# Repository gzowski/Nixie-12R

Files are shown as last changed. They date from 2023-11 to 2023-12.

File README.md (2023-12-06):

# Nixie-12R - Keyboard/GamePad

* Available to purchase from: https://www.etsy.com/uk/shop/PhoenixCustomBoards

* 11 key ortholinear keyboard
* 1 Rotary encoder in the top right
* OLED Display for displaying layer selected
* Pro Micro compatible
  
### [Info](#Info) || [Parts](#Parts) || [Assembly Guide](#Assembly-Guide)

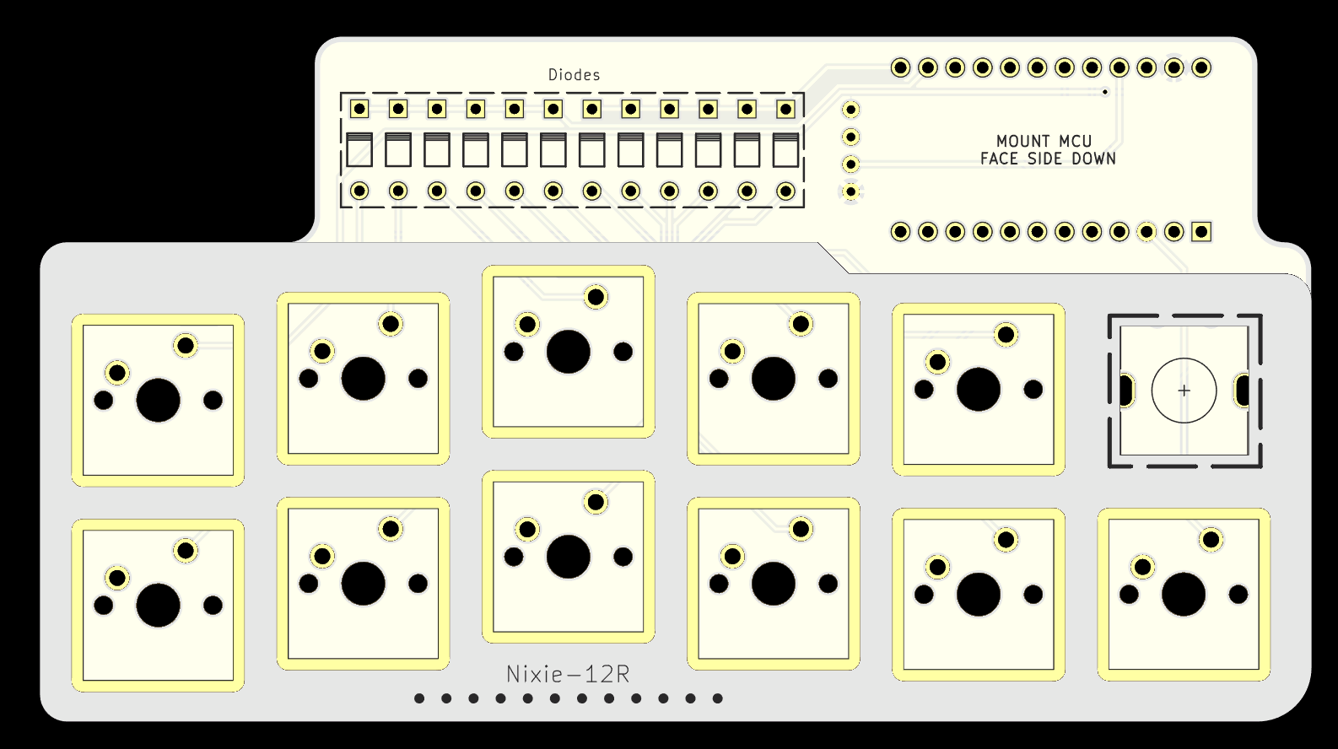
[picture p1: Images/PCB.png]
PCB

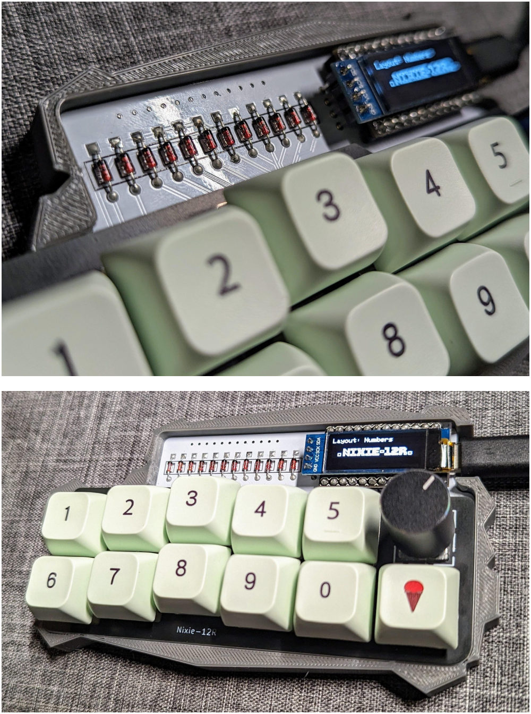
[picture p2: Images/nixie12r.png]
Photos


## Info

* PCB Files within PCB folder, created with KiCad.
* VIA config export and via.json design files in VIA folder
* QMK firmware within QMK/QMK_Firmware/Keyboards/Nixie12r, can be pasted into a local copy of qmk repo and made.
* 3D printable case within Case folder

## Parts

| Part | Quantity | Description | 
| :--- | :--- | :--- |
| Diodes| 12  | Through-hole 1N4148 |
| Microcontroller | 1 | Pro-Micro compatible |
| MX Switches | 11 | Cherry MX compatible switches |
| EC11 | 1 | Rotary Encoder |
| MJTP1117 | 1 | Angled reset switch |
| Keycaps | 1 | 11x1u switches |
| OLED Display | 1 | 128x32 OLED (SSD1306) |

## Assembly Guide

* Insert all switches into the top plate and put to the side
* Diode installation: insert from top of the pcb so diodes are visible from the top
* Reset switch: insert switch on top and solder from underside, remove legs beforehand for clearance.
* Microcontroller needs to be positioned with the top facing the PCB, upsidedown (Test controller beforehand and flash firmware using QMK)
* Place OLED Display on top of PCB and solder from underside.
* Place the rotary encoder on the top side and solder all points ensuring it stays flush to the board.
* Press down the top plate with switches and stabalisers down on the middle plate ensuring that all the switches sit flush against the middle plate.
* Turn board over and proceed to solder switches to the board
* Connect USB to keyboard and check all keys are functional, this is assuming you've already flashed the firmware to the MCU.

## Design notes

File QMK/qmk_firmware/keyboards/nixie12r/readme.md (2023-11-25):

# Nixie-12R
*12 key ortholinear layout with rotary encoder*

* Keyboard Maintainer: [James Gzowski](https://github.com/gzowski)
* Hardware Supported: Pro-Micro or equivilent
* Build Guide: [Nixie-12R](https://github.com/gzowski/nixie-12r)

Make example for this keyboard (after setting up your build environment):
	
    make nixie12r:via

Flashing example for this keyboard:

    make nixie12r:via:flash

See the [build environment setup](https://docs.qmk.fm/#/getting_started_build_tools) and the [make instructions](https://docs.qmk.fm/#/getting_started_make_guide) for more information. Brand new to QMK? Start with our [Complete Newbs Guide](https://docs.qmk.fm/#/newbs).

## Bootloader

* **Bootmagic reset**: Hold down the key at (0,0) in the matrix (usually the top left key or Escape) and plug in the keyboard
* **Physical reset button**: Briefly press the button on the back of the PCB, if using a RP2040 press repeatidly to enter boot mode.
* **Hold down boot loader button on MCU** Hold down the boot loader button on the MCU while plugging in the keyboard

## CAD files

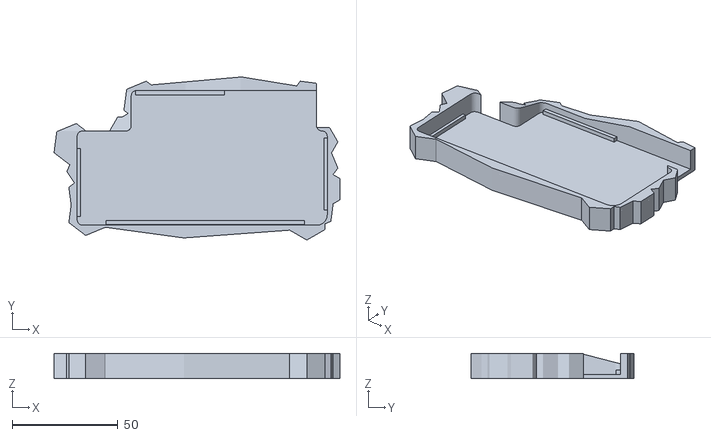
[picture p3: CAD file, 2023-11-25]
Case/case.stl
135.0 x 77.0 x 12.0

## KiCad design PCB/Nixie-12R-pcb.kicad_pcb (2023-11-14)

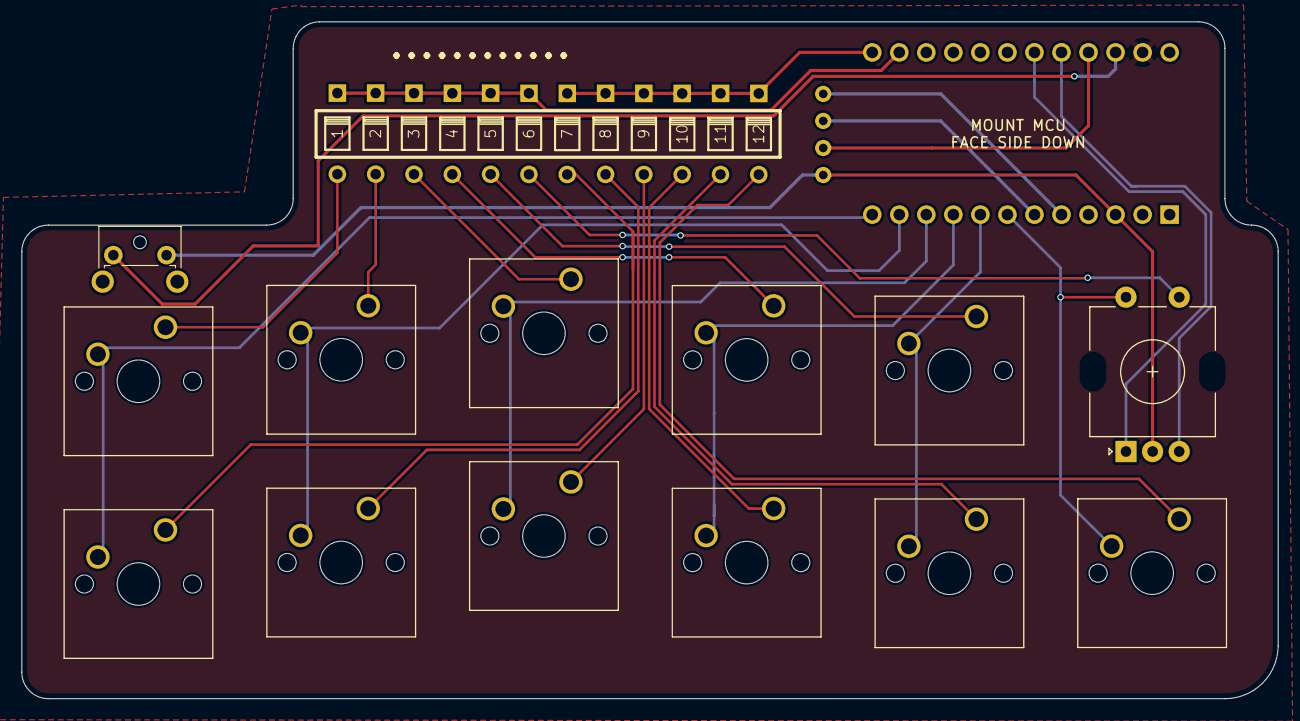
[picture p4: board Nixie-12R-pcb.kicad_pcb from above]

Board: 2 copper layers, 118.1 x 63.6 mm, 27 parts (1 on the bottom side), 27 nets.

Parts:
1, 2: Diode
3, 4, 5, 6, 7, 8, 9, 10, 11, 12: VAL**; Diode
K1, K2, K3, K4, K5, K7, K8, K9, K10, K11, K12: Blank; SW_Cherry_MX_2.00u_PCB
K6-Rotary: RotaryEncoder_EC11
OLED1: OLED; OLED_v2.1
RST: SW_PUSH; SW_Tactile_SPST_Angled_MJTP1117
U1: ProMicro; ArduinoProMicro

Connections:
/Col_0: K1.2, K7.2, U1.12
/Col_1: K2.2, K8.2, U1.11
/Col_2: K3.2, K9.2, U1.10
/Col_3: K4.2, K10.2, U1.9
/Col_4: K5.2, K11.2, U1.8
/Col_5: K12.2, U1.7
/Row_0: 1.2, 2.2, 3.2, 4.2, 5.2, 6.2, U1.14
/Row_1: 7.2, 8.2, 9.2, 10.2, 11.2, 12.2, U1.13
GND2: K6-Rotary.C, OLED1.4, U1.3
unnamed: 1.1, K1.1
unnamed: 2.1, K2.1
unnamed: 3.1, K3.1
unnamed: 4.1, K4.1
unnamed: 5.1, K5.1
unnamed: 6.1, K6-Rotary.S1
unnamed: 7.1, K7.1
unnamed: 8.1, K8.1
unnamed: 9.1, K9.1
unnamed: 10.1, K10.1
unnamed: 11.1, K11.1
unnamed: 12.1, K12.1
ROTDEC: K6-Rotary.A, U1.19
ROTINC: K6-Rotary.B, U1.20
RST: RST.1, U1.22
SDA: OLED1.1, U1.5
SDL: OLED1.2, U1.6
VCC: OLED1.3, U1.21

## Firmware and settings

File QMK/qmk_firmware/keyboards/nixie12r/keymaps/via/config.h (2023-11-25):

// Copyright 2023 QMK
// SPDX-License-Identifier: GPL-2.0-or-later
#pragma once

#define QUICK_TAP_TERM 0
#define TAPPING_TERM 100
#define ENCODER_RESOLUTION 4
#define OLED_FADE_OUT
#define OLED_TIMEOUT 30000
#define OLED_BRIGHTNESS 128

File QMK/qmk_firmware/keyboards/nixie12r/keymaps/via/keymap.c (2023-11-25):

// Copyright 2023 James Gzowski
// SPDX-License-Identifier: GPL-2.0-or-later
#include QMK_KEYBOARD_H

enum custom_layer {
    _LAYERQ,
    _LAYERN,
    _LAYERF
};

const uint16_t PROGMEM keymaps[][MATRIX_ROWS][MATRIX_COLS] = {
    [_LAYERQ] = LAYOUT_2x6(
        KC_Q , KC_W  ,KC_E   ,KC_R   , KC_T  , KC_MUTE,
        KC_A  , KC_S , KC_D , KC_F, KC_G, KC_H
),
    [_LAYERN] = LAYOUT_2x6(
        KC_1 , KC_2  ,KC_3   ,KC_4   , KC_5  , KC_MUTE,
        KC_6  , KC_7 , KC_8 , KC_9, KC_0, KC_MINUS
),
    [_LAYERF] = LAYOUT_2x6(
        KC_F1 , KC_F2  ,KC_F3   ,KC_F4   , KC_F5  , KC_MUTE,
        KC_F6  , KC_F7 , KC_F8 , KC_F9, KC_F10, KC_F11
)
};

#if defined(ENCODER_MAP_ENABLE)
const uint16_t PROGMEM encoder_map[][NUM_ENCODERS][NUM_DIRECTIONS] = {
    [_LAYERQ] = { ENCODER_CCW_CW(TO(_LAYERF), TO(_LAYERN))},
    [_LAYERN] =  { ENCODER_CCW_CW(TO(_LAYERQ), TO(_LAYERF))},
    [_LAYERF] =  { ENCODER_CCW_CW(TO(_LAYERN), TO(_LAYERQ))}
};
#endif

#ifdef OLED_ENABLE

layer_state_t layer_state_set_user(layer_state_t state) {
    return state;
}

static void render_logo(void) {
    static const char PROGMEM my_logo[] = {
       0,  0,  0,  0,  0,  0,  0,  0,  0,  0,  0,  0,  0,  0,  0,  0,  0,254,254,254,140, 24, 48, 96,254,254,254,  0, 14, 14, 14,250,242,250, 14, 14, 14,  0,  6, 30,250,242,254, 48, 48,254,242,250, 30,  6,  0, 14, 14, 14,250,242,250, 14, 14, 14,  0,254,254,242,250,254,206,206,206,206, 14,  0,224, 32, 32, 32, 32,224,  0, 14, 14, 14,250,242,254,  0,  0,  0,  0,142,202,202,238,238,254,254,254,124, 56,  0,254, 50,122,254,206,206,206,254,124, 56,  0,  0,  0,  0,  0,  0,  0,  0,  0,  0,  0,  0,  0,  0,  0,  0,  0,  0,
       0,  0,  0,  0,  0,  0,  0,  0,  0, 31, 17, 17, 17, 31,  0,  0,  0, 31, 31, 31,  1,  3,  6, 12, 31, 31, 31,  0, 28, 28, 28, 23, 19, 23, 28, 28, 28,  0, 24, 30, 23, 19, 31,  3,  3, 31, 19, 23, 30, 24,  0, 28, 28, 28, 23, 19, 23, 28, 28, 28,  0, 31, 31, 19, 23, 31, 28, 28, 28, 28, 28,  0,  1,  1,  1,  1,  1,  1,  0, 28, 28, 28, 23, 19, 23, 28, 28, 28,  0, 31, 19, 23, 31, 29, 29, 20, 20, 28, 24,  0, 31, 30, 31, 31,  1,  1,  1, 31, 23, 19, 30,  0,  0, 31, 17, 17, 17, 31,  0,  0,  0,  0,  0,  0,  0,  0,  0,  0,
    };
oled_write_raw_P(my_logo, sizeof(my_logo));
}

bool oled_task_user(void) {
	switch (get_highest_layer(layer_state)) {
	case _LAYERQ:
	oled_write_ln_P(PSTR("Layout: QWERTY\n"), false);
	break;
        case _LAYERN:
 	oled_write_ln_P(PSTR("Layout: Numbers\n"), false);
	break;
	case _LAYERF:
    	oled_write_ln_P(PSTR("Layout: F1-F11 Keys\n"), false);
	break;
	default:
    	oled_write_ln_P(PSTR("Layout: UNDEF\n"), false);
	break;
	}
	render_logo();
    	return true;
}

#endif
void keyboard_post_init_user(void) {
setPinInput(B0);
writePinLow(B0);
setPinInput(D5);
writePinLow(D5);
};

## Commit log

2023-11-14 Tue Nov 14 11:46:46 AM GMT 2023
    [Nixie-12R-base-B_Cu.gbl, Nixie-12R-base-B_Mask.gbs, Nixie-12R-base-B_Paste.gbp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]
2023-11-25 Sat Nov 25 11:00:44 PM GMT 2023
    [Middle_Plate.step, Middle_Plate2.step, case.stl]
2023-11-25 Sat Nov 25 11:06:48 PM GMT 2023
    [Middle_Plate.step, Middle_Plate2.step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]
